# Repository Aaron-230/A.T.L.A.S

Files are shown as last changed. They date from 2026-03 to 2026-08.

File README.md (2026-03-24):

# A.T.L.A.S.
A.T.L.A.S. or the **A**tmospheric **T**elemetry & **L**ocalized **A**nalytic **S**ystem is a Weather Station which sends Air Quality, Humidity, Temperature, Barometric Sensors Data to an Local, Selfhosted NodeMCU Web Server with the advantage of Portability using Batteries. It interprets and reacts with the weather using an OLED Display which shows expressions like the EMO Robot.
## Why I Made this Project?
I Made this Project because we need to know about our surroundings, the air which we breathe, the Temperature and the Humidity and like most of us, we want to know whether it will rain or not. For this, The Data is represented in an Detailed, Easy to Understand form and for quicker and cutness look, the tiny OLED Screen will show different emotions or faces according to the given data. This can also be helpful for some people as the People with Lung Diseases can benefit for this as it sends out Air Quality Data which helps them to see whether the air is safe for them to breathe or not.
## Screenshots
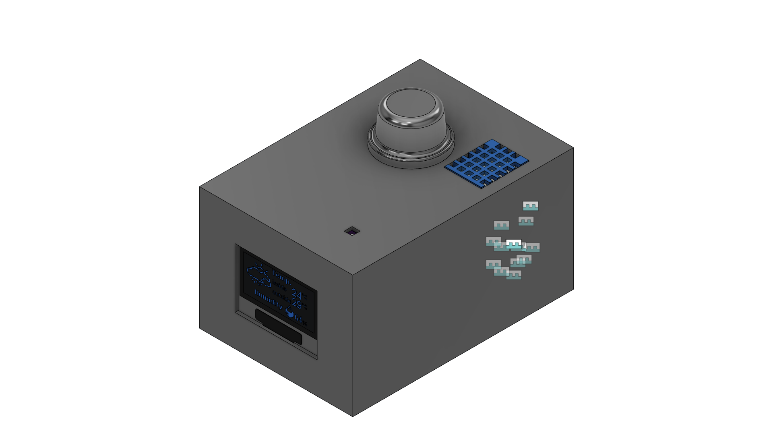
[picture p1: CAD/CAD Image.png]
If you are able to see this, The Image did not load. Please Try Again

## Wiring Diagram
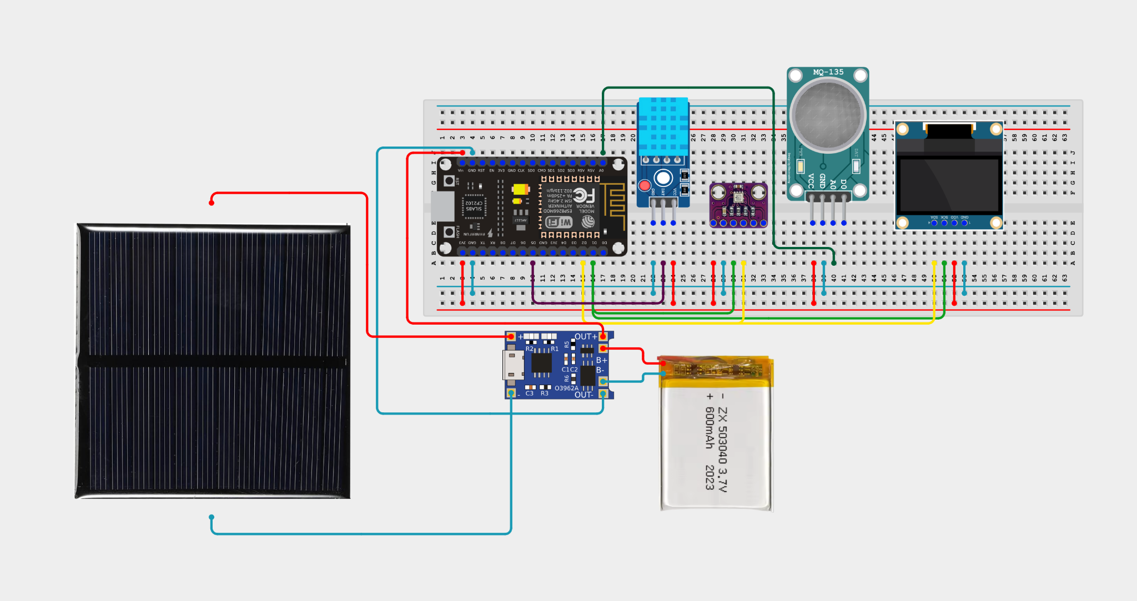
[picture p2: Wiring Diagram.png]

## BOM (Bill of Materials) 
| Name | Purpose | Quantity | Total Cost (USD) | Link | Distributor |
|---|---|---|---|---|---|
| Mini Epoxy Solar Panel | Recharger | 1 | 0.62 | https://robocraze.com/products/mini-epoxy-solar-panel-70x70-mm?_pos=1&_psq=Solar&_ss=e&_v=1.0 | Robocraze |
| 3.7V 1000mAh 1S LiPo Battery | Battery | 1 | 4.02 | https://robu.in/product/wly394058-1000mah-3-7v-single-cell-rechargeable-lipo-battery/ | Robu |
| TP4056 | Battery Charger | 1 | 0.15 | https://robocraze.com/products/tp4056-battery-charger-c-type-module-with-protection-1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 | Robocraze |
| MQ-135 Gas Sensor | Air Quality Sensor | 1 | 1.10 | https://robocraze.com/products/mq-135-gas-sensor-module?_pos=1&_sid=4f0cc67d9&_ss=r | Robocraze |
| BMP280 | Barometric Pressure sensor | 1 | 0.32 | https://robocraze.com/products/bmp280-sensor-module?_pos=4&_sid=80bdb05fe&_ss=r | Robocraze |
| OLED Display | Display | 1 | 2.23 | https://robocraze.com/products/0-96in-oled-display-module-4pin | Robocraze |
| DHT11 | Humidity and Temperature Sensor | 1 | 0.59 | https://robocraze.com/products/dht11-humidity-temperature-sensor-module?_pos=1&_sid=d6ff24292&_ss=r | Robocraze |
| NodeMCU | Microcontroller | 1 | 2.12 | https://robocraze.com/products/lolin-nodemcu-esp8266-wifi-module | Robocraze |

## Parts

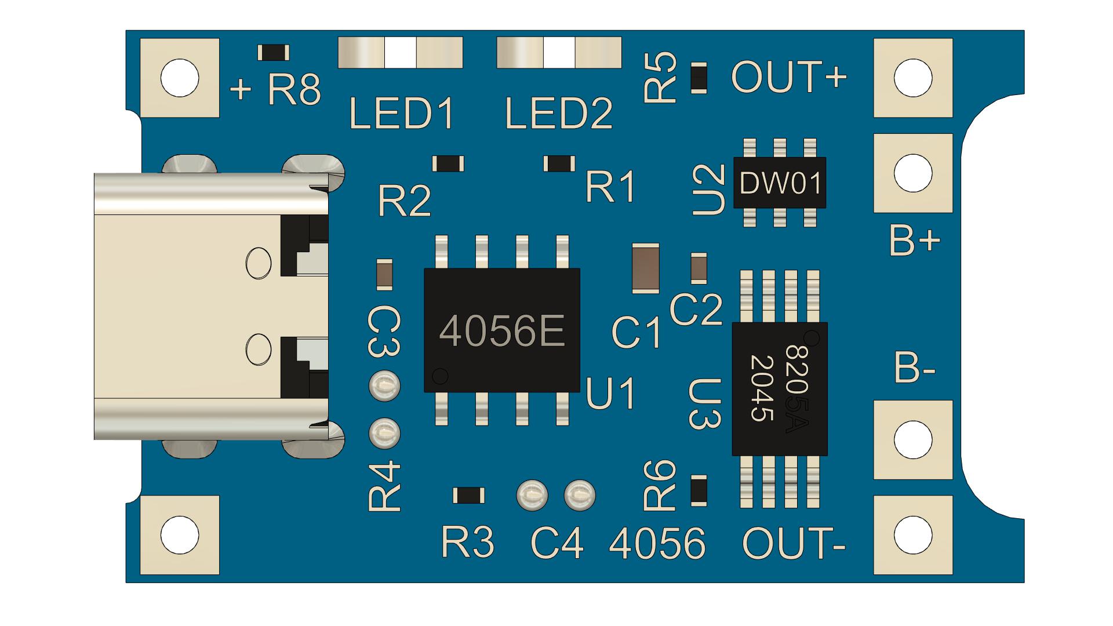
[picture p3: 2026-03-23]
CAD/Parts/tp4056-charging-module-2.snapshot.1/TP4056_Charging_Module_Type_C_Top_View.jpg

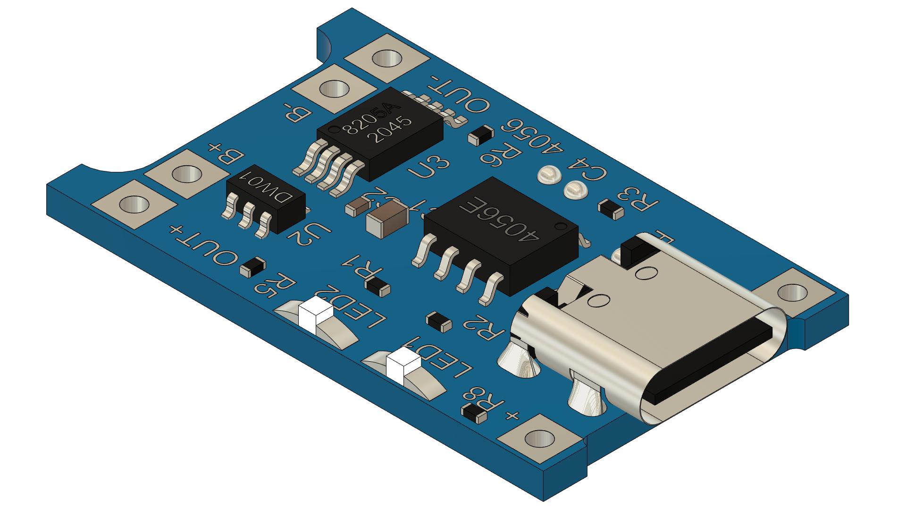
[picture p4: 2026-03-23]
CAD/Parts/tp4056-charging-module-2.snapshot.1/TP4056_Charging_Module_Type_C.jpg

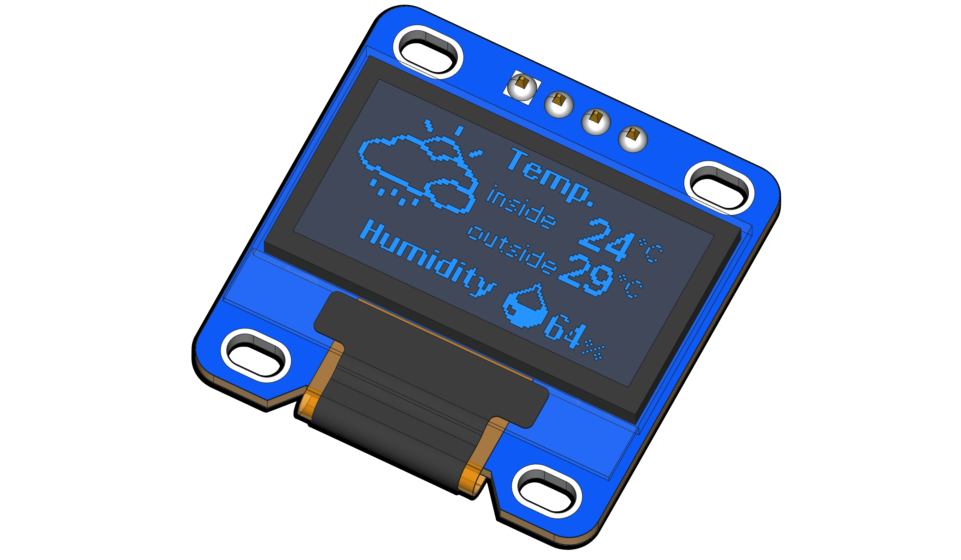
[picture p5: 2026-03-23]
CAD/Parts/oled-display-128-x-64-i2c-0-96-1.snapshot.7/Display.png

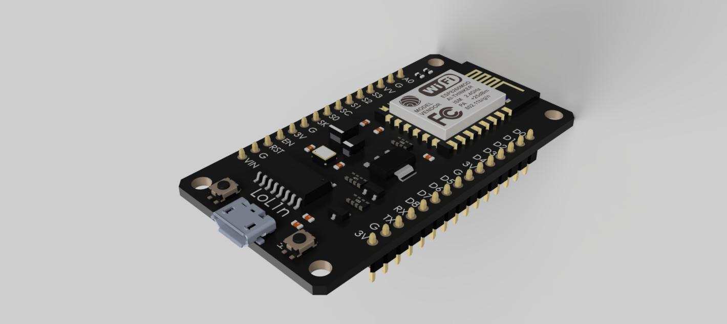
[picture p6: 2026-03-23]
CAD/Parts/esp8266-microcontroller-1.snapshot.3/ESP8266.png

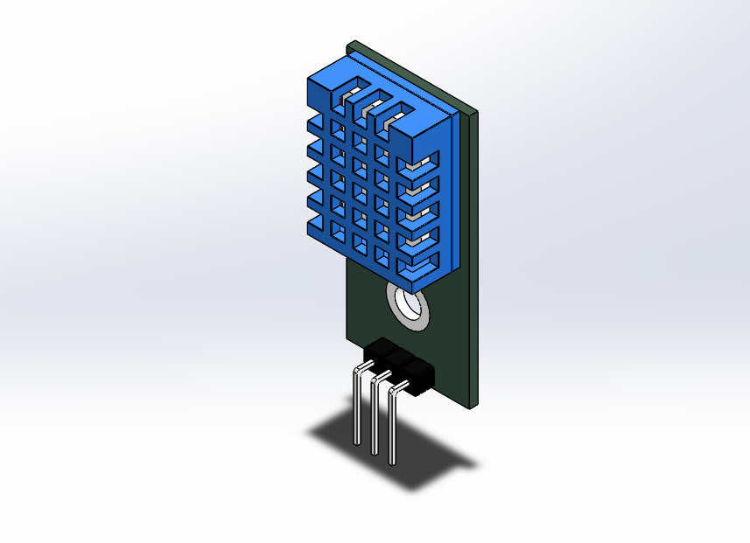
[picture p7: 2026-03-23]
CAD/Parts/dht11-module-1.snapshot.1/DHT11 module/dht11.PNG

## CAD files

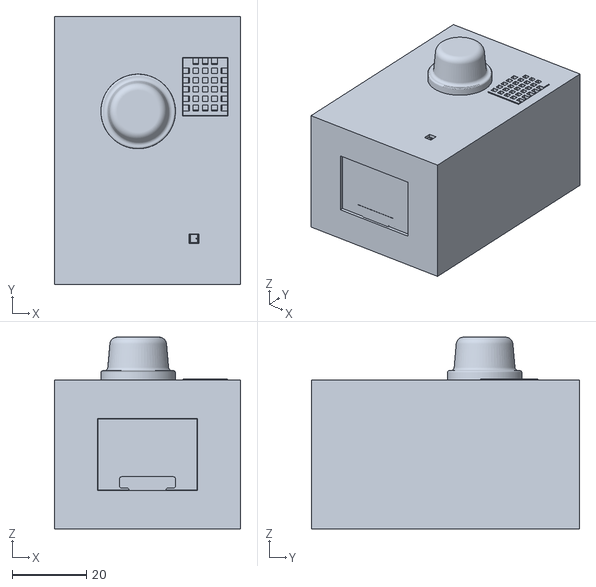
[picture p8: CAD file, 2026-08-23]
CAD/CAD.stl
50.0 x 72.0 x 51.5

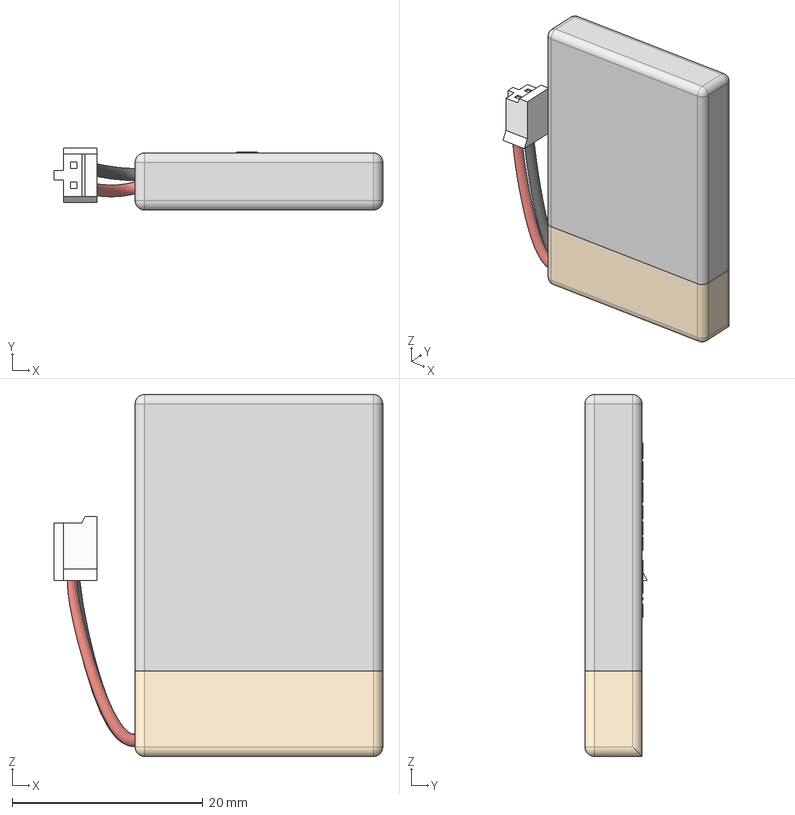
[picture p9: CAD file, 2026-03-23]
CAD/Parts/3-7v-500mah-lipo-battery-1.snapshot.1/3.3V 500Mah Battery v2.step
34.5 x 6.52 x 38.0 mm
Black wIRE
Red Wire
Connector
Text
Text (1)

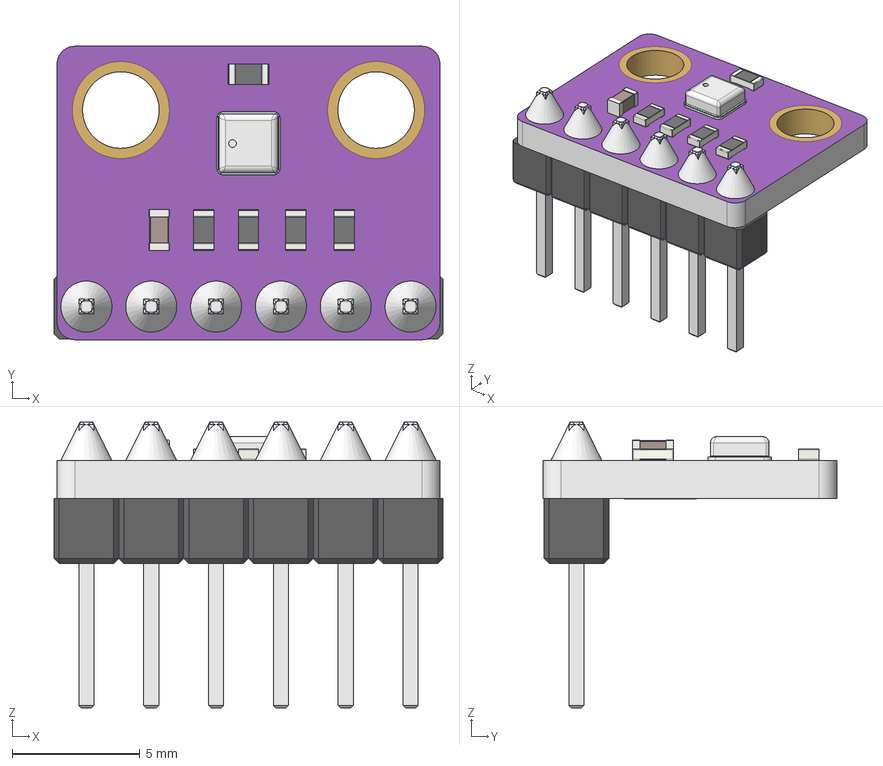
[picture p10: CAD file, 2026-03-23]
CAD/Parts/bme280-6.snapshot.1/BME280_6_pins_3V3.step
15.2 x 11.5 x 11.2 mm
PCB
BME280
R_0603_1608Metric
R_0603_1608Metric001
R_0603_1608Metric002
R_0603_1608Metric003
R_0603_1608Metric004
C_0603_1608Metric
Pin x 6

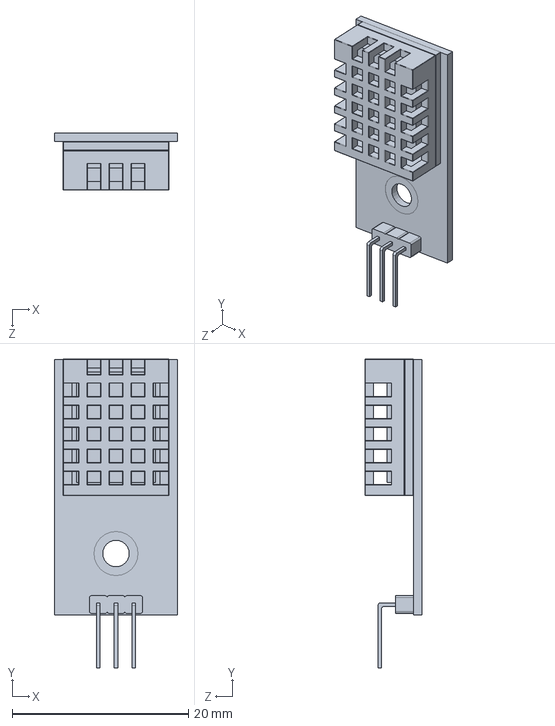
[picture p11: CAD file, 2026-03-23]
CAD/Parts/dht11-module-1.snapshot.1/DHT11 module/DHT11.SLDPRT
14.0 x 35.0 x 6.50 mm

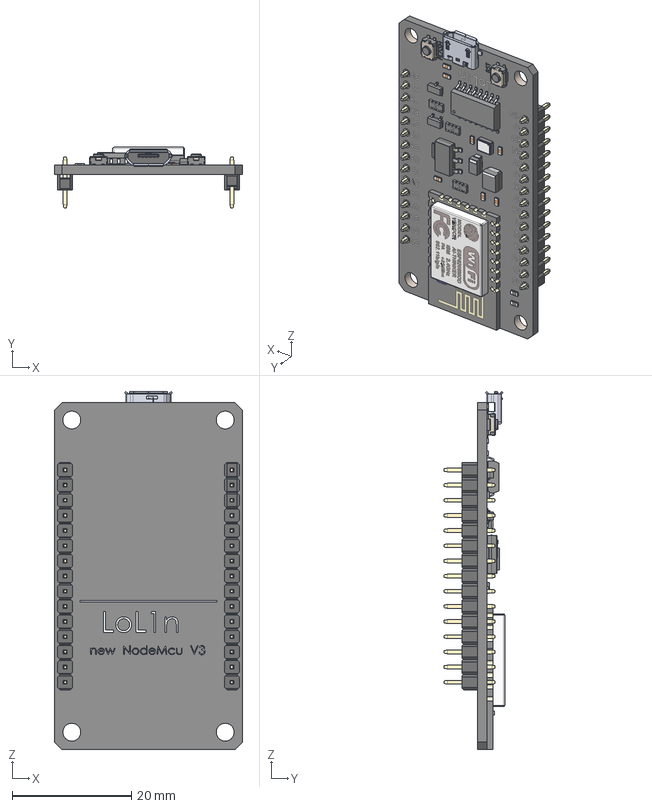
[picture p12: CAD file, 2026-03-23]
CAD/Parts/esp8266-microcontroller-1.snapshot.3/ESP8266.step
31.5 x 10.1 x 60.0 mm
1x4 Male Pin Header x 6
1x3 Male Pin Header x 2
ESP8266 V3

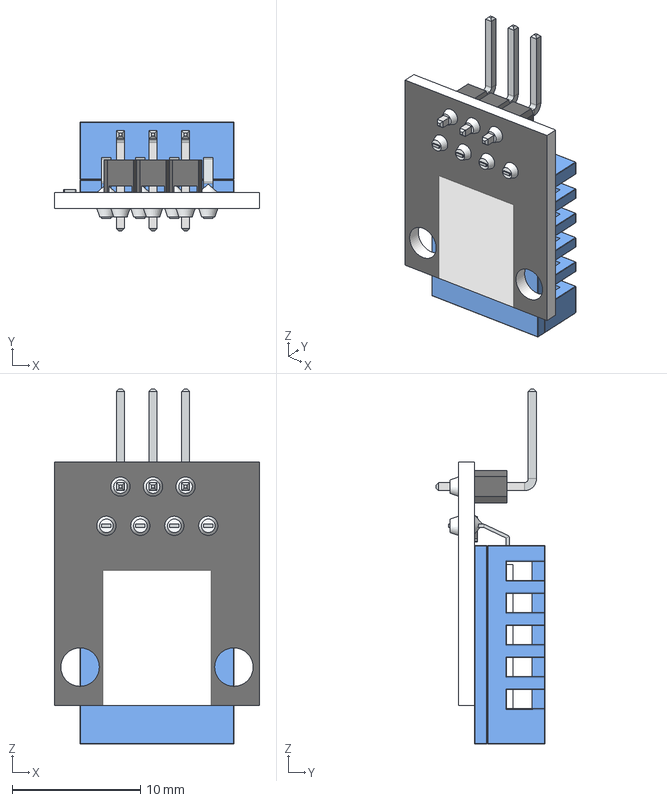
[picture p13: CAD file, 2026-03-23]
CAD/Parts/ky-015-dht11-1.snapshot.1/KY-015.step
16.0 x 8.50 x 27.7 mm

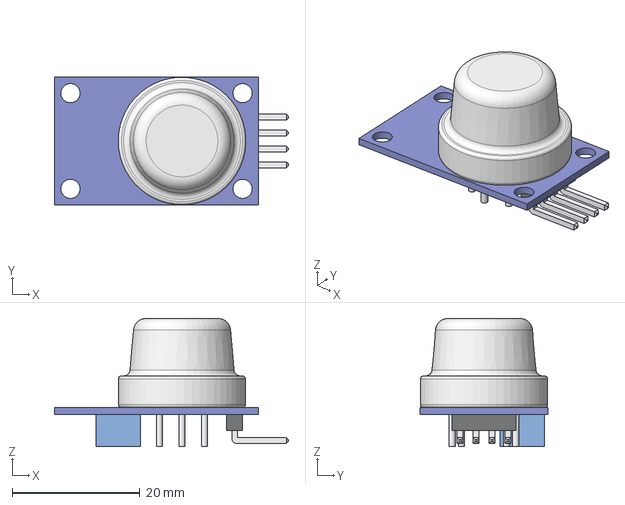
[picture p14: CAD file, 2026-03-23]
CAD/Parts/mq135-air-sensor-1.snapshot.1/MQ135_sensor.step
36.7 x 20.0 x 20.1 mm

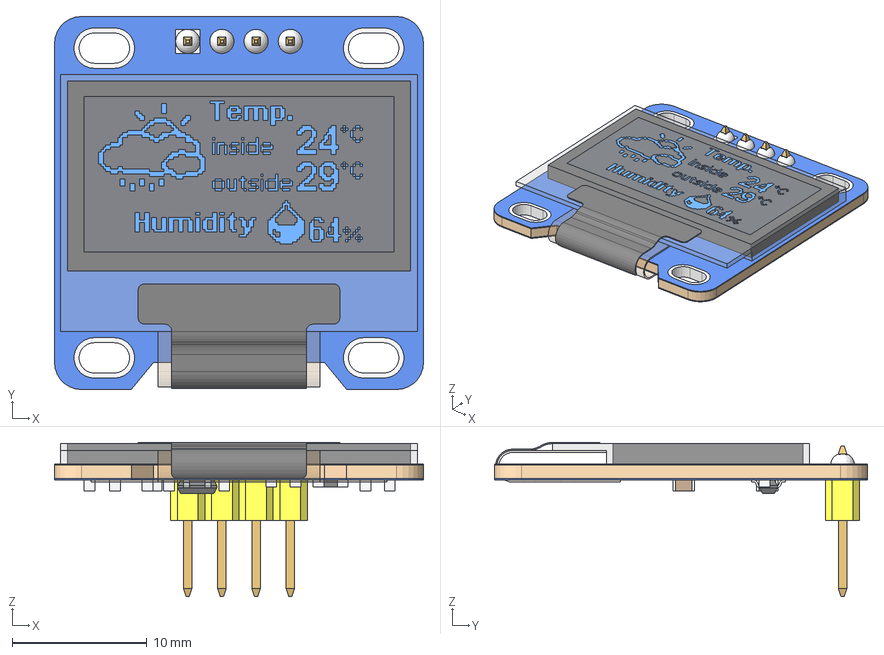
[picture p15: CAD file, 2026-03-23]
CAD/Parts/oled-display-128-x-64-i2c-0-96-1.snapshot.7/OLED 128 x 64 Display 0.96 Inch.step
27.4 x 27.7 x 11.5 mm

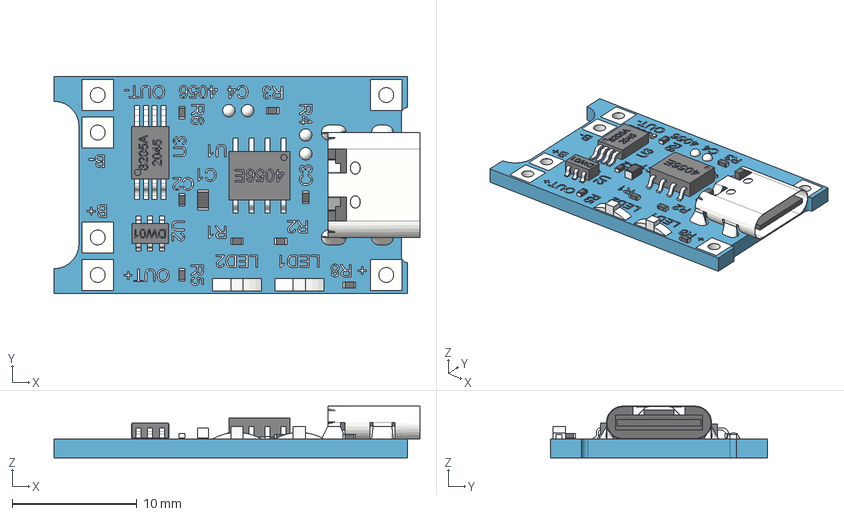
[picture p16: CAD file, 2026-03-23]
CAD/Parts/tp4056-charging-module-2.snapshot.1/TP4056_Charging_Module_Type_C.step
29.3 x 17.4 x 4.14 mm
board
USB_Type_C_Connector
8205A_2045
DW01-P
small1005_smd_resistor x 2
small1005_smd_resistor (1)
small1005_smd_capacitor
smd_capacitor
SOP-8_4056E
solder_dot_round
solder_dot_round (1)
solder_dot_round (2)
solder_dot_round (3)
small1005_smd_capacitor (1)
LED2
LED2 (1)
small1005_smd_resistor (2)
small1005_smd_resistor (4) x 2
soldering

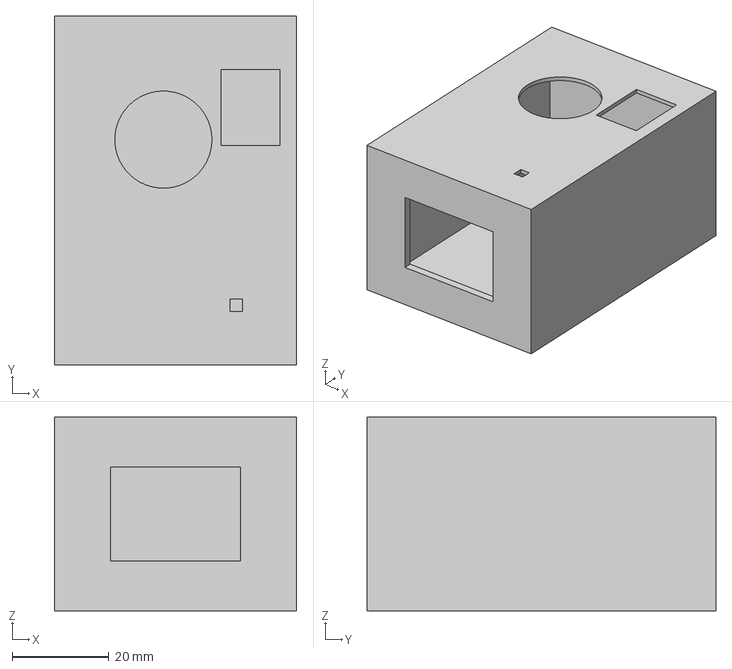
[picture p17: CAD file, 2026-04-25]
CAD/Print.step
50.0 x 72.0 x 40.0 mm

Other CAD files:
CAD/Parts/dht11-module-1.snapshot.1/DHT11 module/DHT11 module.STEP
CAD/Parts/mq135-air-sensor-1.snapshot.1/MQ135_sensor.f3d
CAD/Parts/mq135-air-sensor-1.snapshot.1/MQ135_sensor.iges
CAD/Parts/mq135-air-sensor-1.snapshot.1/MQ135_sensor.stl
CAD/Parts/oled-display-128-x-64-i2c-0-96-1.snapshot.7/OLED 128 x 64 Display 0.96 Inch.FCStd
CAD/Parts/tp4056-charging-module-2.snapshot.1/TP4056_Charging_Module_Type_C.f3d
CAD/Print.stl

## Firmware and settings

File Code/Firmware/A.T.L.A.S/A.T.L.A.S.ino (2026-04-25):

#include <ESP8266WiFi.h>
#include <ESP8266WebServer.h>
#include <DHT.h>
#include <Wire.h>
#include <Adafruit_Sensor.h>
#include <Adafruit_BMP280.h>
#include <Adafruit_GFX.h>
#include <Adafruit_SSD1306.h>

// --- Revised Pin Definitions ---
#define DHTPIN 2          // GPIO 2  (D4) - DHT Data
#define OLED_SDA 4        // GPIO 4  (D2) - OLED SDA
#define OLED_SCL 5        // GPIO 5  (D1) - OLED SCL
#define BMP_SDA 14        // GPIO 14 (D5) - BMP SDA
#define BMP_SCL 12        // GPIO 12 (D6) - BMP SCL
#define MQ135_PIN A0
#define DHTTYPE DHT11

Adafruit_SSD1306 display(128, 64, &Wire, -1);
DHT dht(DHTPIN, DHTTYPE);
Adafruit_BMP280 bmp; 
ESP8266WebServer server(80);

float t = 0, h = 0, p = 0;
int airQuality = 0;
unsigned long lastEyeAnimate = 0;
unsigned long lastGazeShift = 0;
unsigned long lastBlinkTrigger = 0;
int curEyeX = 0, curEyeY = 0, targetEyeX = 0, targetEyeY = 0;
int emotion = 0; 
bool isBlinking = false;

// --- Animation Engine ---
void drawEyes(int offsetX, int offsetY, bool blink, int state) {
  display.clearDisplay();
  int eyeW = 22; int eyeH = 28; int eyeR = 7;
  int eyeY = 18 + offsetY; 
  int leftX = 32 + offsetX; int rightX = 72 + offsetX;
  
  if (blink) {
    display.fillRoundRect(leftX, eyeY + 12, eyeW, 5, 2, WHITE);
    display.fillRoundRect(rightX, eyeY + 12, eyeW, 5, 2, WHITE);
  } else if (state == 1) { // HOT
    display.fillRoundRect(leftX, eyeY + 8, eyeW, 20, 5, WHITE);
    display.fillRoundRect(rightX, eyeY + 8, eyeW, 20, 5, WHITE);
    display.fillRect(leftX, eyeY - 5, eyeW, 13, BLACK);
    display.fillRect(rightX, eyeY - 5, eyeW, 13, BLACK);
  } else if (state == 2) { // ALERT
    display.fillRoundRect(leftX - 2, eyeY - 4, eyeW + 4, eyeH + 8, 11, WHITE);
    display.fillRoundRect(rightX - 2, eyeY - 4, eyeW + 4, eyeH + 8, 11, WHITE);
  } else if (state == 3) { // COLD
    int shiver = (millis() % 100 < 50) ? 1 : -1;
    display.fillRoundRect(leftX + shiver, eyeY + 10, eyeW, 10, 3, WHITE);
    display.fillRoundRect(rightX + shiver, eyeY + 10, eyeW, 10, 3, WHITE);
  } else { // NEUTRAL
    display.fillRoundRect(leftX, eyeY, eyeW, eyeH, eyeR, WHITE);
    display.fillRoundRect(rightX, eyeY, eyeW, eyeH, eyeR, WHITE);
  }
  display.display();
}

int moveTowards(int current, int target, int step) {
  if (current < target) return current + step;
  if (current > target) return current - step;
  return current;
}

// --- Web UI with Degree C ---
const char INDEX_HTML[] PROGMEM = R"rawtext(
<!DOCTYPE html>
<html>
<head>
  <meta name="viewport" content="width=device-width, initial-scale=1">
  <style>
    body { font-family: 'Segoe UI', sans-serif; background-color: #0f0f0f; color: white; display: flex; justify-content: center; align-items: center; min-height: 100vh; margin: 0; }
    .container { background: #1a1a1a; padding: 30px; border-radius: 30px; width: 300px; text-align: center; box-shadow: 0 10px 30px rgba(0,0,0,0.5); }
    .card { background: #222; margin: 10px 0; padding: 20px; border-radius: 20px; }
    .val { font-size: 32px; font-weight: bold; display: block; }
    .label { font-size: 12px; color: #888; text-transform: uppercase; letter-spacing: 1px; }
  </style>
</head>
<body>
  <div class="container">
    <h2>A.T.L.A.S.</h2>
    <div class="card"><span class="val" id="t" style="color:#ff7675">--</span><span class="label">Temperature</span></div>
    <div class="card"><span class="val" id="h" style="color:#74b9ff">--</span><span class="label">Humidity</span></div>
    <div class="card"><span class="val" id="p" style="color:#a29bfe">--</span><span class="label">Pressure</span></div>
    <div class="card"><span class="val" id="a" style="color:#ffeaa7">--</span><span class="label">Air Quality</span></div>
  </div>
  <script>
    setInterval(() => {
      fetch('/data').then(r => r.json()).then(d => {
        document.getElementById('t').innerHTML = d.t + "&deg;C";
        document.getElementById('h').innerText = d.h + "%";
        document.getElementById('p').innerText = d.p + " hPa";
        document.getElementById('a').innerText = d.a + " PPM";
      });
    }, 2000);
  </script>
</body>
</html>
)rawtext";

void handleRoot() { server.send(200, "text/html", INDEX_HTML); }
void handleData() {
  String json = "{\"t\":\"" + String(t, 1) + "\",\"h\":\"" + String(h, 0) + 
                "\",\"p\":\"" + String(p, 1) + "\",\"a\":\"" + String(airQuality) + "\"}";
  server.send(200, "application/json", json);
}

void setup() {
  Serial.begin(115200);
  dht.begin();

  // Initialize OLED (I2C Bus 1)
  Wire.begin(OLED_SDA, OLED_SCL);
  display.begin(SSD1306_SWITCHCAPVCC, 0x3C);

  // Initialize BMP280 (I2C Bus 2)
  Wire.begin(BMP_SDA, BMP_SCL);
  if (!bmp.begin(0x76)) { bmp.begin(0x77); }

  WiFi.softAP("A.T.L.A.S.", "Password");
  server.on("/", handleRoot);
  server.on("/data", handleData);
  server.begin();
}

void loop() {
  server.handleClient();
  unsigned long currentMillis = millis();

  // Read DHT & MQ135
  float newT = dht.readTemperature();
  float newH = dht.readHumidity();
  if (!isnan(newT)) t = newT;
  if (!isnan(newH)) h = newH;
  airQuality = analogRead(MQ135_PIN);

  // BMP280 Bus Switch
  Wire.begin(BMP_SDA, BMP_SCL);
  p = bmp.readPressure() / 100.0F;
  
  // Emotion Updates
  if (airQuality > 550) emotion = 2;
  else if (t > 32) emotion = 1;
  else if (t < 18) emotion = 3;
  else emotion = 0;

  // OLED Animation Bus Switch
  if (currentMillis - lastEyeAnimate >= 35) {
    lastEyeAnimate = currentMillis;
    if (currentMillis - lastGazeShift >= random(3000, 7000)) {
      lastGazeShift = currentMillis;
      targetEyeX = random(-6, 7);
      targetEyeY = random(-4, 5);
    }
    if (currentMillis - lastBlinkTrigger >= random(4000, 10000)) {
      lastBlinkTrigger = currentMillis;
      isBlinking = true;
    }
    if (isBlinking && (currentMillis - lastBlinkTrigger > 120)) isBlinking = false;

    curEyeX = moveTowards(curEyeX, targetEyeX, 1);
    curEyeY = moveTowards(curEyeY, targetEyeY, 1);

    Wire.begin(OLED_SDA, OLED_SCL);
    drawEyes(curEyeX, curEyeY, isBlinking, emotion);
  }
}

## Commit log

2026-03-23 Created the CAD for the Project
    [3.3V 500Mah Battery v2.step, BME280_6_pins_3V3.step, DHT11 module.STEP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]
2026-03-24 Rearranged in a Neat Manner
    [3.3V 500Mah Battery v2.step, BME280_6_pins_3V3.step, DHT11 module.STEP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]
2026-03-24 Added Wiring Diagram and BOM
    [BOM.csv]
2026-03-24 Updated the Wiring Diagram
2026-04-25 Updated the Firmware and added a Print Version of CAD
    [Print.step]
2026-08-23 Converted .STEP to .STL
    [CAD.stl, Print.stl]
